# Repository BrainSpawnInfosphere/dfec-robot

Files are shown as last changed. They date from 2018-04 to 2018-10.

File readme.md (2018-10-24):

# DFEC Robot

## Example Software

The example SW is written for the Arduino and is found in `robot-2` as an example.

## Hardware

Frame developed using [OpenScad](http://www.openscad.org/)

[Base plate](base.stl)

[Motor mounts](motor.stl)

## Motors

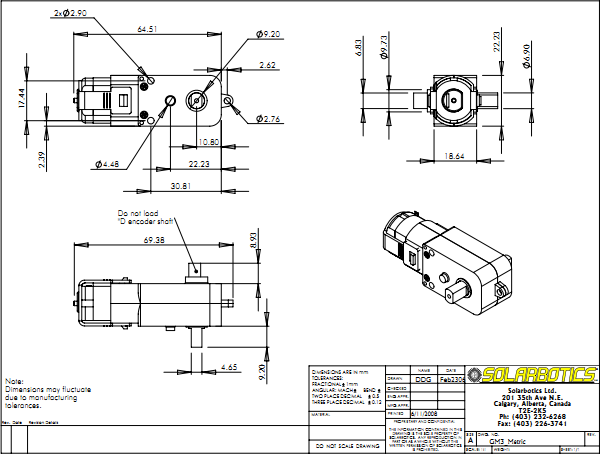
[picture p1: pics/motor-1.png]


## PCB

PCB version 4 is the current version.

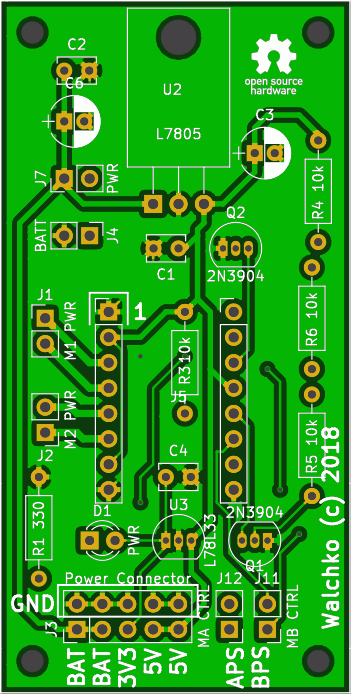
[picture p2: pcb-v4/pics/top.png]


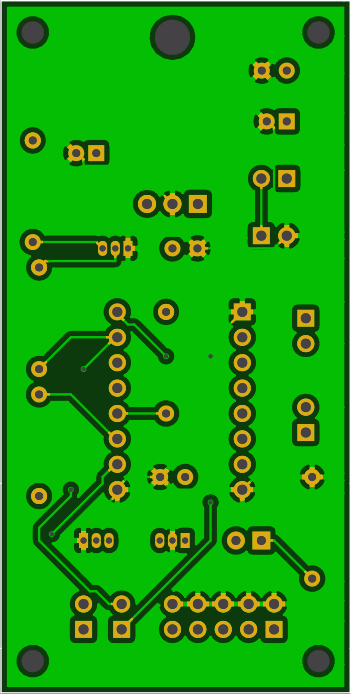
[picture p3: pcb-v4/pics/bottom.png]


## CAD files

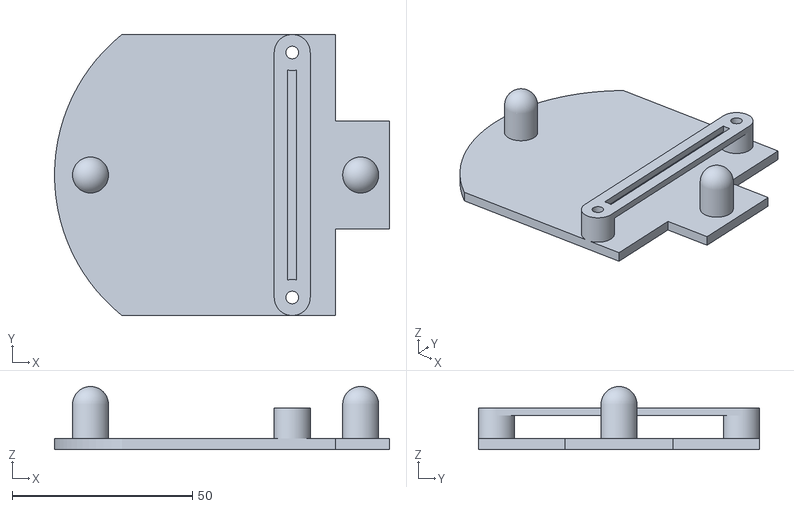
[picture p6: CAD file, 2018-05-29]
base.stl
93.0 x 78.0 x 17.5

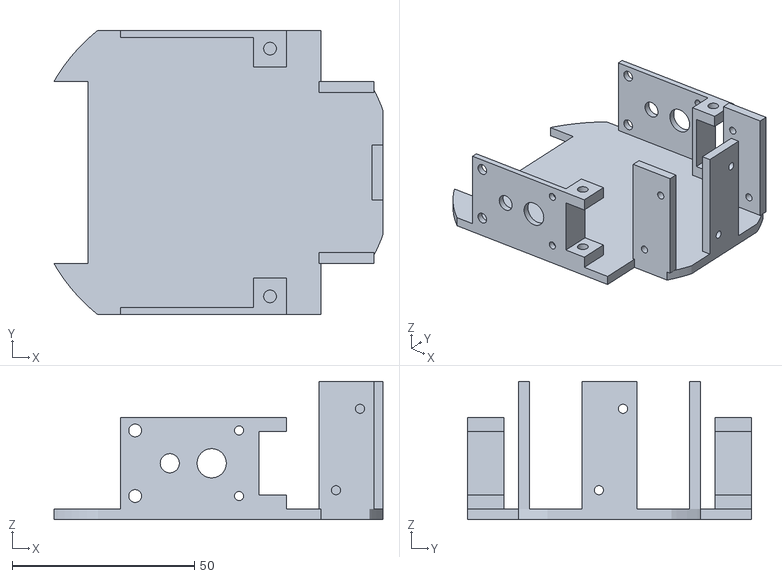
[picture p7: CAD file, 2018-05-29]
motor.stl
90.3 x 78.0 x 38.0

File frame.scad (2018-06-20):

$fn=100;

hole_440 = 3.5;  // mm
hole_256 = 2.5;  // mm

module plate(thick=3){
    difference(){
        dia = 100;
        cylinder(thick,d=dia, center=true);
        translate([-dia/2,dia/2-10,-thick]) cube([dia,dia,2*thick]);
        translate([-dia/2,-3*dia/2+10,-thick]) cube([dia,dia,2*thick]);
    }
}

module irholes(){
    translate([0,2.1,2.1]) rotate([0,-90,0]){
        cylinder(10,d=hole_256,center=true);
        translate([0,0,-1]) cylinder(10,d=2.5*hole_256,center=false);
    }
    translate([0,10.8-2.1,23.4+2.1/2+2]) rotate([0,-90,0]){
        cylinder(10,d=hole_256,center=true);
        translate([0,0,-1]) cylinder(10,d=2.5*hole_256,center=false);
    }
    translate([-5,8,-1]) cube([10,7,12]);  // connector
}

module ir_mnt(){
    translate([0,-15/2,0]) difference(){
        cube([3,13,30]);
        translate([0,2.5,1]) irholes();
    }
}

module wheel(){
    color("gray") rotate([90,0,0]) cylinder(h=8, d=60.1);
}

module board(){
    color("green") translate([-70/2, -35/2, 0]) cube([70,35,2]);
    color("green") translate([-10, -7.5, 0]) cube([20,15,19]);
}

module board_mnt(){
    // won't work like this!!!
    // solder bumps on the back will push it up higher
    w = 20;
    dia = 5;
    difference(){
        rotate([0,90,0]) cylinder(h=w,d=dia, center=true);
        translate([-w,0,-dia/4]) cube([2*w,dia,dia/2]);  // groove
        translate([-w,-dia/2,-dia/2]) cube([2*w,dia,dia/2]);  // cut off bottom
    }
}

//board_mnt();

module motor_straight(){
    difference(){
        union(){
            // gears
            translate([0,-18.8/2,-22.4/2]) cube([36.8, 18.8, 22.4]);
            // motor
            rotate([0,90,0]) translate([0,0,-22.9]) cylinder(h=22.9, d=18.8);
            // shaft
            translate([25.6,0,0]) rotate([-90,0,0]) cylinder(h=18.8/2+9.2,d=5.4);
            // nubbin
            translate([36.8-22.3,0,0]) rotate([-90,0,0]) cylinder(h=18.8/2+2,d=4.48);
        }
        // mounting holes
        translate([36.8-31.8,0,9]) rotate([-90,0,0]) cylinder(h=50.4,d=hole_440,center=true);
        translate([36.8-31.8,0,-9]) rotate([-90,0,0]) cylinder(h=50,d=hole_440,center=true);
    }
}

module motor_90(){
    difference(){
        union(){
            // gears
            translate([-22.5/2,-13.7/2,-22.8/2]) cube([42,13.7,22.8]);
            // motor
            rotate([90,0,0]) translate([0,0,13.72/2]) cylinder(d=22.5, h=33);
            // shaft
            translate([20.6,0,0]) rotate([-90,0,0]) cylinder(h=18.8/2+9.2,d=5.4);
            // nubbin
            translate([9.5,0,0]) rotate([-90,0,0]) cylinder(h=18.8/2+2,d=4.48);
        }
        // mounting holes
        translate([28.5,0,9]) rotate([-90,0,0]) cylinder(h=25,d=hole_256,center=true);
        translate([28.5,0,-9]) rotate([-90,0,0]) cylinder(h=25,d=hole_256,center=true);
    }
}

module motor_mnt(){
    height = 25;
    difference(){
        // main L shape of bracket
        union(){
            translate([-5,0,0]) cube([40,2,height]);
            translate([31.5,-8,0]) cube([9,10,height]);
        }
        
        // cut out in verticle square pillar
        translate([33,-8-1,.3*height/2]) cube([12,12,0.7*height]);
        
        // mounting hole verticle
        translate([36,-3,.2*height/2]) cylinder(h=100, d=hole_440, center=true);
        
        // motor shaft
        translate([20,0,height/2]) rotate([90,0,0]) cylinder(d=8, h=10, center=true);
        
        // nubbin
        translate([8.5,0,height/2]) rotate([90,0,0]) cylinder(d=5.25, h=10, center=true);
        
        // mounting holes
        translate([19.5,0,height/2]) rotate([90,0,0]){
            // 90
            translate([8,9,0]) cylinder(d=hole_256, h=10, center=true);
            translate([8,-9,0]) cylinder(d=hole_256, h=10, center=true);
            // straight
            translate([-20.5,9,0]) cylinder(d=hole_440, h=10, center=true);
            translate([-20.5,-9,0]) cylinder(d=hole_440, h=10, center=true);
        }
    }
}

module breadboard(){
    cube([54,83,10]);
}

module caster(){
    // 18.6 mm w/o thick
    dia = 10;
    h = 16;
    cylinder(h=h-dia/2, d=dia);
    translate([0,0,h-dia/2]) sphere(d=dia);
}

thick = 3;


module motor_plate_90(thick, draw=false){
    // main plate
    color("lightblue") difference()
    {
        cylinder(h=thick,d=100, center=true);
        
        // cut outs for the wheels
        translate([0,49,0]) cube([65,30,10], center=true);
        translate([0,-49,0]) cube([65,30,10], center=true);
    }
    
    // motor mounts
    translate([-20,32,thick/2]) color("lightblue") motor_mnt();
    rotate([180,180,0]) translate([-20,32,thick/2]) color("lightblue") motor_mnt();
    
    // IR sensors
//    translate([47,0,0]) ir_mnt();
//    rotate([0,0,30]) translate([47,0,0]) ir_mnt();
//    rotate([0,0,-30]) translate([47,0,0]) ir_mnt();
    
    
    if (draw){
        translate([0,0,22.8/2+thick/2]){
            translate([-21,25,1]){
                rotate([0,0,0]) motor_90();
//                translate([20.6,20,0]) wheel();
            }
            translate([21,-25,1]){
                rotate([180,180,0]){
                    motor_90();
//                    translate([20.6,20,0]) wheel();
                }
            }
        }
    }
}

module array_mnt(width){
    h = 10;
    t = 2;
    difference(){
        union(){
            translate([0,width/2,0]) cylinder(h=h,d=10);
            translate([0,-width/2,0]) cylinder(h=h,d=10);
            difference(){
                translate([-5,-width/2,h-t]) cube([10,width,t]);
                translate([-hole_256/2,-width/2,h-2*t]) cube([hole_256,width,3*t]);
            }
        }
        translate([0,width/2,0]) cylinder(h=6*h,d=hole_440, center=true);
        translate([0,-width/2,0]) cylinder(h=6*h,d=hole_440, center=true);
    }
}

module base_plate_90(thick, draw=false){
    // plate
    color("lightgray") difference()
    {
        cylinder(h=thick,d=100, center=true);
        translate([0,49,0]) cube([65,30,10], center=true);
        translate([0,-49,0]) cube([65,30,10], center=true);
        
        // holes
        translate([16,29,0]) cylinder(h=10,d=hole_440, center=true);
        translate([-16,-29,0]) cylinder(h=10,d=hole_440, center=true);
    }
    
    // caster wheels
    translate([40,0,0]) caster();
    translate([-40,0,0]) caster();
    
    // line following array
    translate([25,0,0]) array_mnt(55);
}

//motor_plate_90(thick, true);
//translate([0,0,28]) base_plate_90(thick);
//base_plate_90(thick);

//motor_mnt();

//caster();

module base_plate_s(thick, draw=false){
    // plate
    color("lightblue") difference()
    {
        cylinder(h=thick,d=100, center=true);
        
        // IR cuts
        translate([48,0,0]) cube([10,50,10], center=true);  // front
        translate([28,15,-thick]) cube([35,50,10], center=false);  // robot right
        translate([28,-15,thick]) rotate([180,0,0]) cube([35,50,10], center=false);  // robot left
        
        // wheel cuts
        translate([0,57,0]) cube([65,30,10], center=true);
        translate([0,-57,0]) cube([65,30,10], center=true);
        
        // holes
        translate([16,37,0]) cylinder(h=10,d=hole_440, center=true);
        translate([16,-37,0]) cylinder(h=10,d=hole_440, center=true);
        
        // electronics board holes
        translate([-43,35/2-3,0]) cylinder(h=10,d=hole_256, center=true);
        translate([-43,-35/2+3,0]) cylinder(h=10,d=hole_256, center=true);
        translate([63-43,35/2-3,0]) cylinder(h=10,d=hole_256, center=true);
        translate([63-43,-35/2+3,0]) cylinder(h=10,d=hole_256, center=true);
    }
    
<<<<<<< HEAD
    if (draw){
        // electronics board
=======
    // electronics board
    if (draw){
>>>>>>> aa75e32dec23ce2409879322cab7f08783aae942
        translate([-10,0,-thick/2-1]) rotate([180,0,0]) board();
    }
    
    // caster wheels
    translate([35,0,0]) caster();
    translate([-40,0,0]) caster();
    
    // line following array
//    translate([16,0,0]) array_mnt(68);
}
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

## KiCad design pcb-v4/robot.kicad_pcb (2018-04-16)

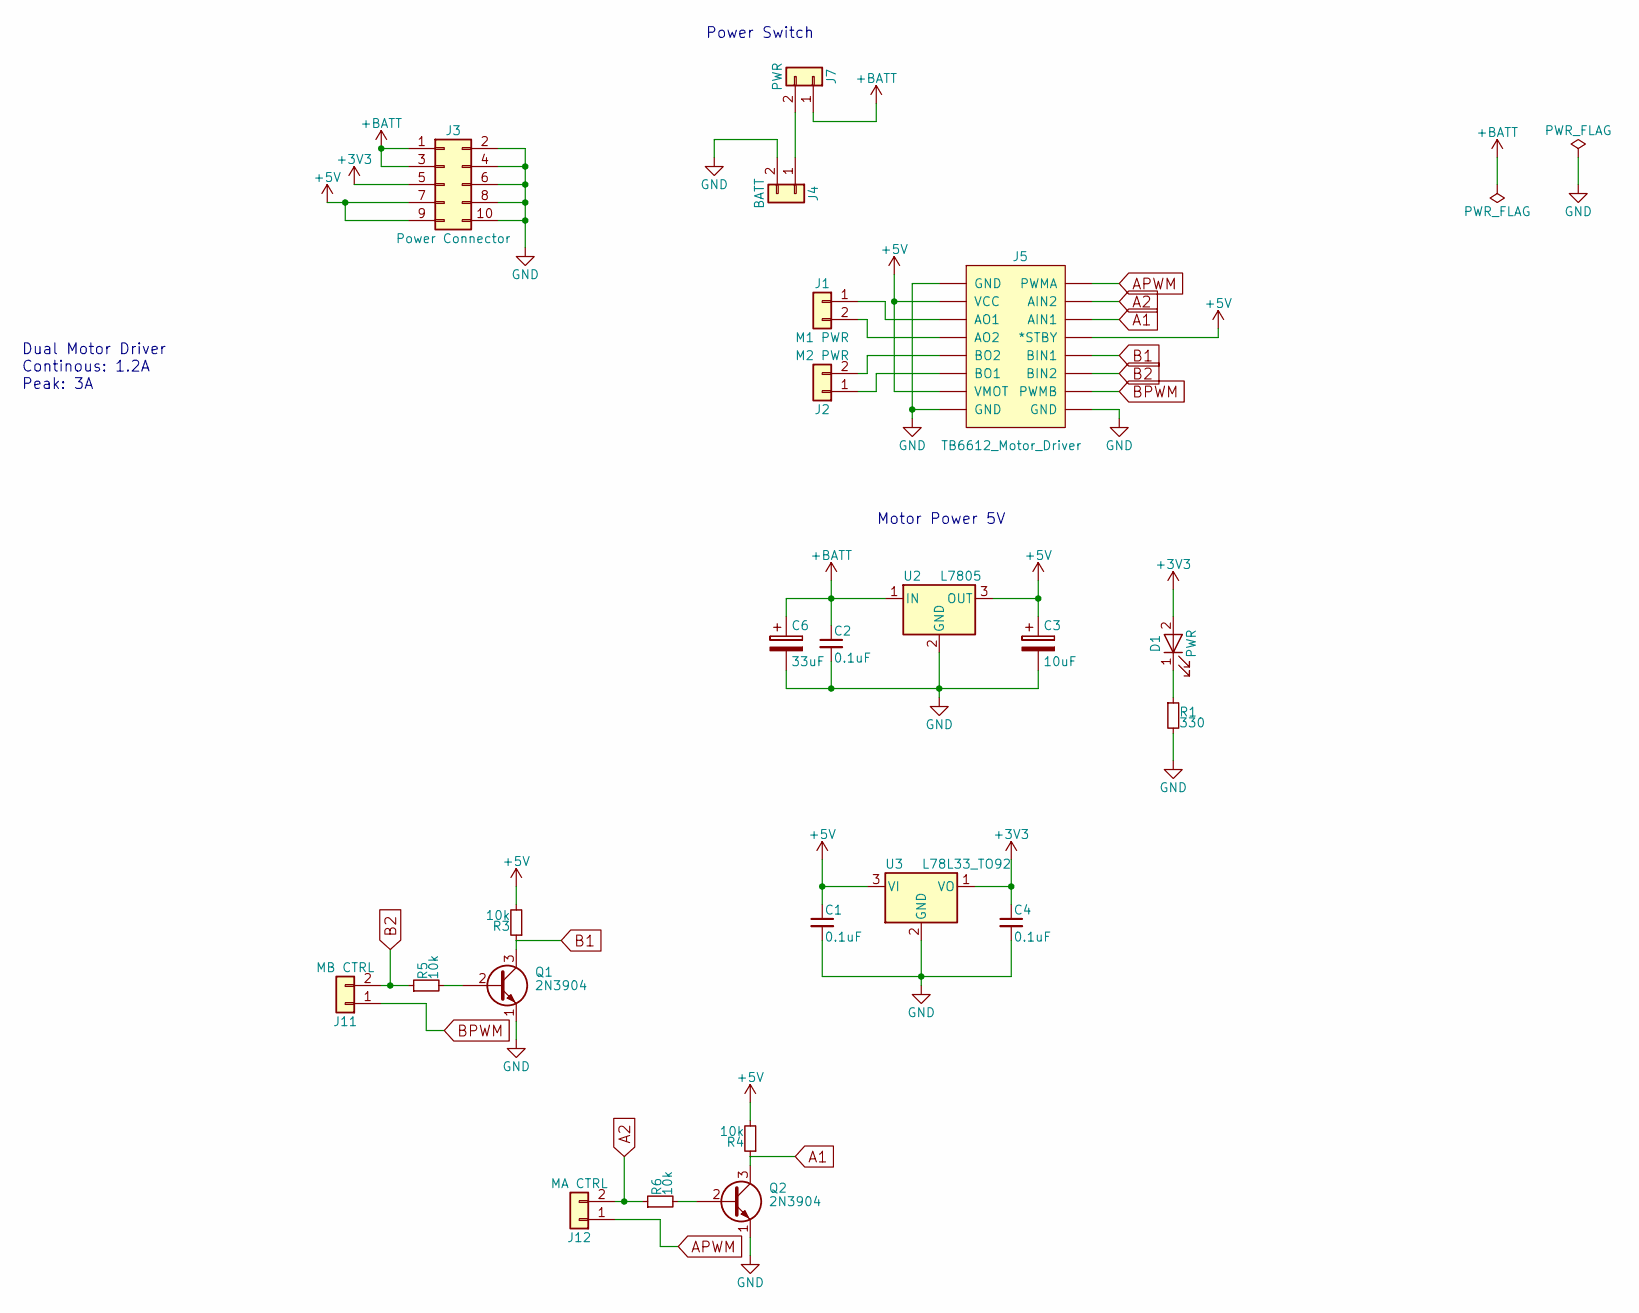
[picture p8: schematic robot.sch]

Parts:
C1, C2, C4: 0.1uF; C_Disc_D3.8mm_W2.6mm_P2.50mm
C3: 10uF; CP_Radial_D5.0mm_P2.00mm
C6: 33uF; CP_Radial_D5.0mm_P2.00mm
D1: PWR; LED_D3.0mm
J1: M1 PWR; Pin_Header_Straight_1x02_Pitch2.54mm
J2: M2 PWR; Pin_Header_Straight_1x02_Pitch2.54mm
J3: Power Connector; Pin_Header_Straight_2x05_Pitch2.54mm
J4: BATT; Pin_Header_Straight_1x02_Pitch2.54mm
J5: TB6612_Motor_Driver; Pololu_TB6612
J7: PWR; Pin_Header_Straight_1x02_Pitch2.54mm
J11: MB CTRL; Pin_Header_Straight_1x02_Pitch2.54mm
J12: MA CTRL; Pin_Header_Straight_1x02_Pitch2.54mm
Q1, Q2: 2N3904; TO-92_Inline_Narrow_Oval
R1: 330; R_Axial_DIN0207_L6.3mm_D2.5mm_P10.16mm_Horizontal
R3, R4, R5, R6: 10k; R_Axial_DIN0207_L6.3mm_D2.5mm_P10.16mm_Horizontal
U2: L7805; TO-220-3_Horizontal
U3: L78L33_TO92; TO-92_Inline_Narrow_Oval

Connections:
+3V3: C4.1, D1.2 (A), J3.5, U3.1 (VO)
+5V: C1.1, C3.1, J3.7, J3.9, J5.2 (VCC), J5.7 (VMOT), J5.13 (*STBY), R3.2, R4.2, U2.3 (OUT), U3.3 (VI)
+BATT: C2.1, C6.1, J3.1, J3.3, J7.1, U2.1 (IN)
A1: J5.14 (AIN1), Q2.3 (C), R4.1
A2: J5.15 (AIN2), J12.2, R6.1
APWM: J5.16 (PWMA), J12.1
B1: J5.12 (BIN1), Q1.3 (C), R3.1
B2: J5.11 (BIN2), J11.2, R5.1
BPWM: J5.10 (PWMB), J11.1
GND: C1.2, C2.2, C3.2, C4.2, C6.2, J3.2, J3.4, J3.6, J3.8, J3.10, J4.2, J5.1 (GND), J5.8 (GND), J5.9 (GND), Q1.1 (E), Q2.1 (E), R1.2, U2.2 (GND), U3.2 (GND)
unnamed: D1.1 (K), R1.1
unnamed: J1.1, J5.3 (AO1)
unnamed: J1.2, J5.4 (AO2)
unnamed: J2.1, J5.6 (BO1)
unnamed: J2.2, J5.5 (BO2)
unnamed: J4.1, J7.2
unnamed: Q1.2 (B), R5.2
unnamed: Q2.2 (B), R6.2

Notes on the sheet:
Power Switch
Motor Power 5V
Dual Motor Driver Continous: 1.2A Peak: 3A

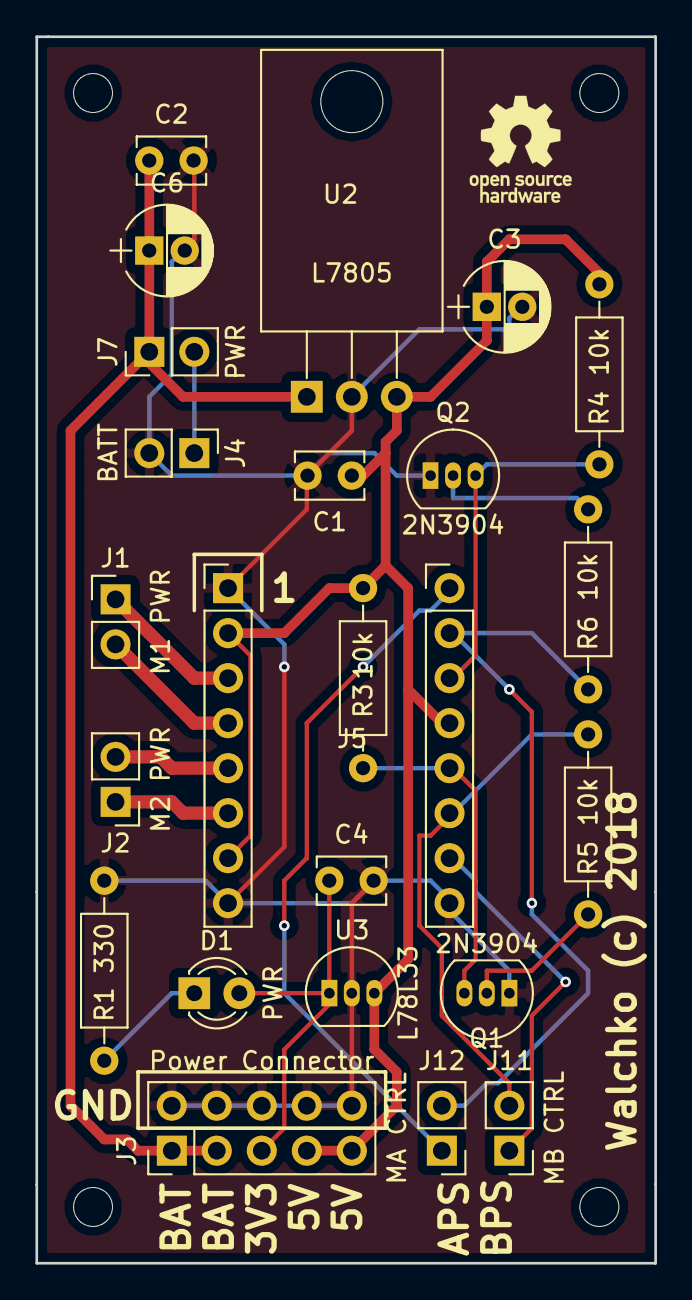
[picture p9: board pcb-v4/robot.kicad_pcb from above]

Board: 2 copper layers, 34.9 x 69.2 mm, 23 parts (0 on the bottom side), 18 nets.

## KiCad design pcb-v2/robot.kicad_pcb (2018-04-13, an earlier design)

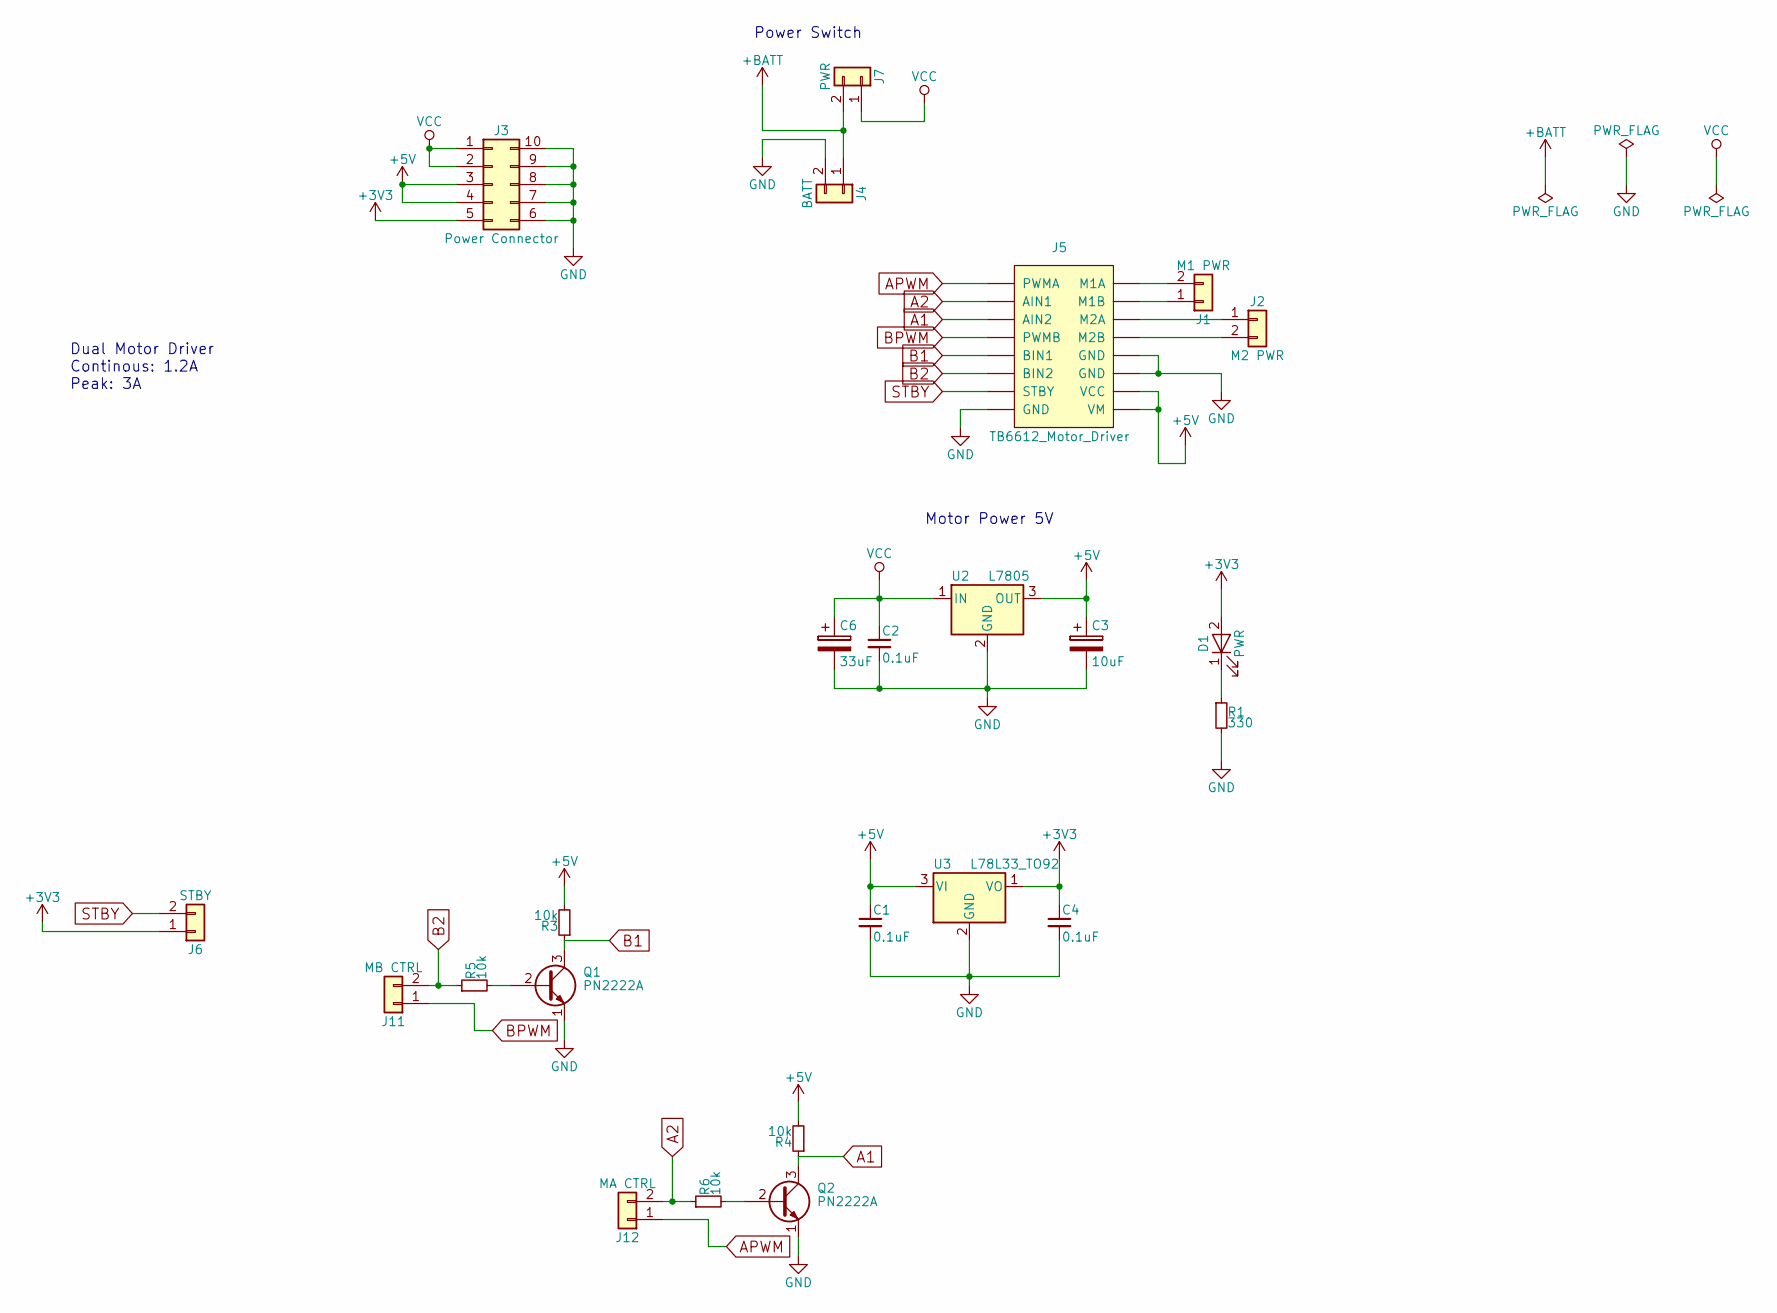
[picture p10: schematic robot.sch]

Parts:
C1, C2, C4: 0.1uF; C_Disc_D3.8mm_W2.6mm_P2.50mm
C3: 10uF; CP_Radial_D5.0mm_P2.00mm
C6: 33uF; CP_Radial_D5.0mm_P2.00mm
D1: PWR; LED_D3.0mm
J1: M1 PWR; Pin_Header_Straight_1x02_Pitch2.54mm
J2: M2 PWR; Pin_Header_Straight_1x02_Pitch2.54mm
J3: Power Connector; Pin_Header_Straight_2x05_Pitch2.54mm
J4: BATT; Pin_Header_Straight_1x02_Pitch2.54mm
J5: TB6612_Motor_Driver; Pololu_TB6612
J6: STBY; Pin_Header_Straight_1x02_Pitch2.54mm
J7: PWR; Pin_Header_Straight_1x02_Pitch2.54mm
J11: MB CTRL; Pin_Header_Straight_1x02_Pitch2.54mm
J12: MA CTRL; Pin_Header_Straight_1x02_Pitch2.54mm
Q1, Q2: PN2222A; TO-92_Inline_Narrow_Oval
R1: 330; R_Axial_DIN0204_L3.6mm_D1.6mm_P5.08mm_Horizontal
R3, R4, R5, R6: 10k; R_Axial_DIN0204_L3.6mm_D1.6mm_P5.08mm_Horizontal
U2: L7805; TO-220-3_Horizontal
U3: L78L33_TO92; TO-92_Inline_Narrow_Oval

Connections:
+3V3: C4.1, D1.2 (A), J3.5, J6.1, U3.1 (VO)
+5V: C1.1, C3.1, J3.3, J3.4, J5.9 (VM), J5.10 (VCC), R3.2, R4.2, U2.3 (OUT), U3.3 (VI)
+BATT: J4.1, J7.2
A1: J5.3 (AIN2), Q2.3 (C), R4.1
A2: J5.2 (AIN1), J12.2, R6.1
APWM: J5.1 (PWMA), J12.1
B1: J5.5 (BIN1), Q1.3 (C), R3.1
B2: J5.6 (BIN2), J11.2, R5.1
BPWM: J5.4 (PWMB), J11.1
GND: C1.2, C2.2, C3.2, C4.2, C6.2, J3.6, J3.7, J3.8, J3.9, J3.10, J4.2, J5.8 (GND), J5.11 (GND), J5.12 (GND), Q1.1 (E), Q2.1 (E), R1.2, U2.2 (GND), U3.2 (GND)
unnamed: D1.1 (K), R1.1
unnamed: J1.1, J5.15 (M1B)
unnamed: J1.2, J5.16 (M1A)
unnamed: J2.1, J5.14 (M2A)
unnamed: J2.2, J5.13 (M2B)
unnamed: Q1.2 (B), R5.2
unnamed: Q2.2 (B), R6.2
STBY: J5.7 (STBY), J6.2
VCC: C2.1, C6.1, J3.1, J3.2, J7.1, U2.1 (IN)

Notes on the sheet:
Power Switch
Motor Power 5V
Dual Motor Driver Continous: 1.2A Peak: 3A

Board: 2 copper layers, 24 parts (0 on the bottom side), 19 nets, no tracks yet.

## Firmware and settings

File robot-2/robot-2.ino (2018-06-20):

#include <Wire.h>
#include "TB6612FNG.h"

/*
name motors left/right not A/B

*/

//const int a1    = 13;
const int adir    = 12;  // direction a
const int pwma  = 11;  // HW
//const int b1    = 8;
const int bdir    = 9;  // direction b
const int pwmb  = 10; // HW
//const int RESET  = 14;
//const int BEEP   = 15;


class Robot {
public:
	Robot(){
//		motorAB = new MotorDriver(pwma,a1,a2,pwmb,b1,b2);
    motorAB.init(pwma,adir,pwmb,bdir);
    motorAB.begin();
	}
	// dir <xxxx d c b a>  0 - reverse, 1 - forward
	// void setMotors(byte dir, byte a, byte b, byte c, byte d){
	void drive(byte dir, byte a, byte b){
		if(dir & 1) motorAB.motor0Forward(a);
		else motorAB.motor0Reverse(a);

		if(dir & 2) motorAB.motor1Forward(b);
		else this->motorAB.motor1Reverse(b);
	}

	void allStop(){
//		motorAB.coastBothMotors();
//		delay(100);
		motorAB.stopBothMotors();
	}

  int motorTest(int spd){
    spd += 10;
    if(spd>100) spd = 0;
    motorAB.motor0Forward(spd);
    motorAB.motor1Forward(spd);
    delay(1000);
    motorAB.motor0Reverse(spd);
    motorAB.motor1Reverse(spd);

    return spd;
  }

	void run(){
    static int spd = 0;
		// check sensors
		// move motors
//    spd = motorTest(spd);
    delay(1000);
    Serial.println(spd);
//    Serial.println((int)motorAB);
	}

 void turnLeft(int spd){
    motorAB.motor0Forward(spd);
    motorAB.motor1Reverse(spd);
 }
 
  void turnRight(int spd){
    motorAB.motor1Forward(spd);
    motorAB.motor0Reverse(spd);
 }

 void forward(int spd){
    motorAB.motor0Forward(spd);
    motorAB.motor1Forward(spd);
 }
 
  void reverse(int spd){
    motorAB.motor0Reverse(spd);
    motorAB.motor1Reverse(spd);
 }

 void wander(){
  int front = analogRead(0); // green
  int left = analogRead(2); // blue
  int right = analogRead(1); // orange

  int detect = 150;
  int spd = 50;
  int lrturn = 100; // left/right turn time
  int fturn = 1000; // front turn time
  
  Serial.println(front);
  if (front > detect){
    if (left > detect && right > detect){
      turnRight(spd);
      delay(fturn); // try to get 180 with 2 delays
    }
    else if (left > detect){
      turnRight(spd);
      delay(lrturn);
    }
    else {
      turnLeft(spd);
      delay(lrturn);
    }
  }
  else if (left > detect){
      turnRight(spd);
      delay(lrturn);
    }
  else if (right > detect){
      turnLeft(spd);
      delay(lrturn);
    }
  else {
    forward(50);
    delay(100);
  }
 }

private:
  MotorDriver motorAB;
};

Robot *robot = NULL;

//MotorDriver md(pwma,a1,a2,pwmb,b1,b2);
//int spd = 0;

void setup(){
  robot = new Robot();
	Serial.begin(9600);
	Serial.println("hello world");
}


//void mdtest(){
//  int spd = 0;
//  MotorDriver md;
//  md.init(pwma,a1,a2,pwmb,b1,b2);
//  while(true){
//    spd += 10;
//    if(spd>100) spd = 0;
//    md.motor0Forward(spd);
//    md.motor1Forward(spd);
//    delay(1000);
//    md.motor0Reverse(spd);
//    md.motor1Reverse(spd);
//    delay(1000);
//    
//  }
//}


void loop(){
//    mdtest();

  int a = 0;
//	while(true){
//		robot->wander();
    robot->forward(200);
		delay(1000);
    robot->reverse(200);
    delay(1000);
    robot->allStop();
//    a = analogRead(0);
//    Serial.println(a);
//	}
  // cpu trap
  while(true){}
}

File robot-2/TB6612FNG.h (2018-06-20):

#ifndef __TB6612FNG_H__
#define __TB6612FNG_H__

// #include <Arduino.h>
#include <stdint.h>

/**
 * ATmega328P, pwm works on pins 3, 5, 6, 9, 10, and 11 at 490/980Hz
 */
class MotorDriver {
public:

  MotorDriver(void){
    ;
  }
  
  void init(int pwmA, int adir, int pwmB, int bdir, int reset=-1){
    pwmA_pin = pwmA;
    pwmB_pin = pwmB;
    Adir_pin = adir;
    Bdir_pin = bdir;
    reset_pin = reset;

    pinMode(pwmA_pin, OUTPUT);
    pinMode(pwmB_pin, OUTPUT);
    pinMode(Adir_pin, OUTPUT);
    pinMode(Bdir_pin, OUTPUT);

    if(reset_pin){
      pinMode(reset_pin, OUTPUT);
      digitalWrite(reset_pin, HIGH);
    }
  }

  void begin(){
    if(reset_pin){
      digitalWrite(reset_pin, LOW);
      delay(100);
      digitalWrite(reset_pin, HIGH);
    }
  }

  void motor0Forward(uint8_t speed){
//    Serial.println("motor0Forward");
    digitalWrite(Adir_pin,HIGH);
    analogWrite(pwmA_pin, speed);
  }

  void motor1Forward(uint8_t speed){
    digitalWrite(Bdir_pin,HIGH);
    analogWrite(pwmB_pin, speed);
  }

  void motor0Reverse(uint8_t speed){
    digitalWrite(Adir_pin,LOW);
    analogWrite(pwmA_pin, speed);
  }

  void motor1Reverse(uint8_t speed){
    digitalWrite(Bdir_pin,LOW);
    analogWrite(pwmB_pin, speed);
  }

  /**
   * Stop is defined as PWM set to zero.
   */
  void stopBothMotors(){
    stopMotor0();
    stopMotor1();
  }

  void stopMotor0(){
//    digitalWrite(A0_pin,HIGH);
//    digitalWrite(A1_pin,HIGH);
    analogWrite(pwmA_pin, 0);
  }

  void stopMotor1(){
//    digitalWrite(B0_pin,HIGH);
//    digitalWrite(B1_pin,HIGH);
    analogWrite(pwmB_pin, 0);
  }



//  /**
//   * Coast is defined as a high impedance state. No current runs through motors
//   * and they just spin.
//   */
//  void coastBothMotors(){
//    motor0Coast();
//    motor1Coast();
//  }
//
//  void motor0Coast(){
//    digitalWrite(A0_pin,LOW);
//    digitalWrite(A1_pin,LOW);
//    analogWrite(pwmA_pin, 255);
//  }
//
//  void motor1Coast(){
//    digitalWrite(B0_pin,LOW);
//    digitalWrite(B1_pin,LOW);
//    analogWrite(pwmB_pin, 255);
//  }

protected:

  int pwmA_pin, pwmB_pin, Adir_pin, Bdir_pin, reset_pin;
};

#endif

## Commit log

2018-04-15 new version
    [robot-B.Cu.gbr, robot-B.Mask.gbr, robot-B.SilkS.gbr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]
2018-04-16 fixed md footprint and 1/4 w resistors
    [robot-B.Cu.gbr, robot-B.Mask.gbr, robot-B.SilkS.gbr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]
2018-04-16 small fixes
    [robot-B.Cu.gbr, robot-B.Mask.gbr, robot-B.SilkS.gbr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]
2018-05-14 more design mods
    [frame.scad]

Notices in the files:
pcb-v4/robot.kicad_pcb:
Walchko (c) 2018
